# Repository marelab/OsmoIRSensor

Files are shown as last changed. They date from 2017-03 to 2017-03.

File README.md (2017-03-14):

OsmoIRSensor
IR Water &amp; Fluid detection Sensor based on ATTINY45. 
- KiCad Shematic & PCB included under hardware
- Firmware for ATTINY45 included under software

The Sensor was designed for Osmosi waterlevel control. 
It is designed to be full encapsulated in a EPOXY case. 
The hole design an maufacturing process as well as the 
technical backgrounds for the IR detection 
is described under
https://www.marelab.org

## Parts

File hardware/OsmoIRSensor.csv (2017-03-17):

Reference | Value | Footprint | Datasheet | man#
U1 | ATTINY45-S | marelab:SOIC-8 |  | Value
R4 | 10K | Resistors_SMD:R_0805 |  | Value
R3 | 422R | Resistors_SMD:R_0805 |  | Value
R2 | 4K7 | Resistors_SMD:R_0805 |  | Value
R1 | 220R | Resistors_SMD:R_0805 |  | Value
X1 | 20MHz | marelab:RESONATOR |  | Value
D1 | LED PWR | LEDs:LED_0805 |  | Value
D2 | LED IR | LEDs:LED_PLCC-2 |  | Value
U2 | TSOP75436WTR | marelab:SMD-IR |  | Value
J2 | CONN_02X03_PCB_DIRECT | marelab:CON3x2PCB |  | Value
C1 | 22nF | Resistors_SMD:R_0805 |  | Value

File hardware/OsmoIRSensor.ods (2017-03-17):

Reference | Value | Footprint | Datasheet | man# | cost
U1 | ATTINY45-S | marelab:SOIC-8 |  | Value | 1
R4 | 10K | Resistors_SMD:R_0805 |  | Value | 0,1
R3 | 422R | Resistors_SMD:R_0805 |  | Value | 0,1
R2 | 4K7 | Resistors_SMD:R_0805 |  | Value | 0,1
R1 | 220R | Resistors_SMD:R_0805 |  | Value | 0,1
X1 | 20MHz | marelab:RESONATOR |  | Value | 0,5
D1 | LED PWR | LEDs:LED_0805 |  | Value | 0,3
D2 | LED IR | LEDs:LED_PLCC-2 |  | Value | 0,4
U2 | TSOP75436WTR | marelab:SMD-IR |  | Value | 1,1
J2 | CONN_02X03_PCB_DIRECT | marelab:CON3x2PCB |  | Value | 0
C1 | 22nF | Resistors_SMD:R_0805 |  | Value | 0,2
PCB | PCB 1/6 |  |  |  | 0,416666666666667
EpoxyHarz |  |  |  |  | 1,66666666666667
Kabel |  |  |  |  | 6,66666666666667
 |  |  |  | Summe | 12,65

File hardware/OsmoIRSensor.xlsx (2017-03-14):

 |  |  |  |  |  |  | Board Qty: | 100
 |  |  |  |  |  |  | Total Cost: | $0.00 |  |  |  | $0.00 |  |  |  |  |  | $0.00 |  |  |  |  |  | $0.00 |  |  |  |  |  | $0.00
 |  |  |  |  |  |  | Unit Cost: | $0.00
Global Part Info |  |  |  |  |  |  |  |  | Digi-Key |  |  |  |  |  | Mouser |  |  |  |  |  | Newark |  |  |  |  |  | Rs Components
Refs | Value | Desc | Footprint | Manf | Manf# | Qty | Unit$ | Ext$ | Avail | Purch | Unit$ | Ext$ | Cat# | Doc | Avail | Purch | Unit$ | Ext$ | Cat# | Doc | Avail | Purch | Unit$ | Ext$ | Cat# | Doc | Avail | Purch | Unit$ | Ext$ | Cat# | Doc
C1 | 22nF |  | Resistors_SMD:R_0805 |  | Value | 0 | $0.00 | $0.00 |  |  |  |  |  |  | 0 |  | $0.00 | $0.00 | 653-VAL | Link (http://www.mouser.com/Search/../ProductDetail/Omron-Electronics/VAL/?qs=sGAEpiMZZMtzFpQ%252bfsc2VG9FapavGxSS)
IC2 | TSOP75436WTR |  | marelab:SMD-IR |  | Value | 0 | $0.00 | $0.00 |  |  |  |  |  |  | 0 |  | $0.00 | $0.00 | 653-VAL | Link (http://www.mouser.com/Search/../ProductDetail/Omron-Electronics/VAL/?qs=sGAEpiMZZMtzFpQ%252bfsc2VG9FapavGxSS)
IC1 | ATTINY45-S |  | SMD_Packages:SOIC-8-N |  | Value | 0 | $0.00 | $0.00 |  |  |  |  |  |  | 0 |  | $0.00 | $0.00 | 653-VAL | Link (http://www.mouser.com/Search/../ProductDetail/Omron-Electronics/VAL/?qs=sGAEpiMZZMtzFpQ%252bfsc2VG9FapavGxSS)
R2 | 200R |  | Resistors_SMD:R_0805 |  | Value | 0 | $0.00 | $0.00 |  |  |  |  |  |  | 0 |  | $0.00 | $0.00 | 653-VAL | Link (http://www.mouser.com/Search/../ProductDetail/Omron-Electronics/VAL/?qs=sGAEpiMZZMtzFpQ%252bfsc2VG9FapavGxSS)
R3 | 3K |  | Resistors_SMD:R_0805 |  | Value | 0 | $0.00 | $0.00 |  |  |  |  |  |  | 0 |  | $0.00 | $0.00 | 653-VAL | Link (http://www.mouser.com/Search/../ProductDetail/Omron-Electronics/VAL/?qs=sGAEpiMZZMtzFpQ%252bfsc2VG9FapavGxSS)
R4 | 1K |  | Resistors_SMD:R_0805 |  | Value | 0 | $0.00 | $0.00 |  |  |  |  |  |  | 0 |  | $0.00 | $0.00 | 653-VAL | Link (http://www.mouser.com/Search/../ProductDetail/Omron-Electronics/VAL/?qs=sGAEpiMZZMtzFpQ%252bfsc2VG9FapavGxSS)
D1 | LED PWR |  | LEDs:LED_0805 |  | Value | 0 | $0.00 | $0.00 |  |  |  |  |  |  | 0 |  | $0.00 | $0.00 | 653-VAL | Link (http://www.mouser.com/Search/../ProductDetail/Omron-Electronics/VAL/?qs=sGAEpiMZZMtzFpQ%252bfsc2VG9FapavGxSS)
R1 | 10K |  | Resistors_SMD:R_0805 |  | Value | 0 | $0.00 | $0.00 |  |  |  |  |  |  | 0 |  | $0.00 | $0.00 | 653-VAL | Link (http://www.mouser.com/Search/../ProductDetail/Omron-Electronics/VAL/?qs=sGAEpiMZZMtzFpQ%252bfsc2VG9FapavGxSS)
P1 | CONN_02X03_PCB_DIRECT |  | marelab:CON3x2PCB |  | Value | 0 | $0.00 | $0.00 |  |  |  |  |  |  | 0 |  | $0.00 | $0.00 | 653-VAL | Link (http://www.mouser.com/Search/../ProductDetail/Omron-Electronics/VAL/?qs=sGAEpiMZZMtzFpQ%252bfsc2VG9FapavGxSS)
D2 | LED IR |  | LEDs:LED_PLCC-2 |  | Value | 0 | $0.00 | $0.00 |  |  |  |  |  |  | 0 |  | $0.00 | $0.00 | 653-VAL | Link (http://www.mouser.com/Search/../ProductDetail/Omron-Electronics/VAL/?qs=sGAEpiMZZMtzFpQ%252bfsc2VG9FapavGxSS)
Y1 | 20MHz |  | marelab:RESONATOR |  | Value | 0 | $0.00 | $0.00 |  |  |  |  |  |  | 0 |  | $0.00 | $0.00 | 653-VAL | Link (http://www.mouser.com/Search/../ProductDetail/Omron-Electronics/VAL/?qs=sGAEpiMZZMtzFpQ%252bfsc2VG9FapavGxSS)
 |  |  |  |  |  |  |  |  |  | 0 | 0 | 0 |  |  |  | 0 | 0 | 0 |  |  |  | 0 | 0 | 0 |  |  |  | 0 | 0 | 0
 |  |  |  |  |  |  |  |  |  | 0 | 0 | 0 |  |  |  | 0 | 0 | 0 |  |  |  | 0 | 0 | 0 |  |  |  | 0 | 0 | 0
 |  |  |  |  |  |  |  |  |  | 0 | 0 | 0 |  |  |  | 0 | 0 | 0 |  |  |  | 0 | 0 | 0 |  |  |  | 0 | 0 | 0
 |  |  |  |  |  |  |  |  |  | 0 | 0 | 0 |  |  |  | 0 | 0 | 0 |  |  |  | 0 | 0 | 0 |  |  |  | 0 | 0 | 0
 |  |  |  |  |  |  |  |  |  | 0 | 0 | 0 |  |  |  | 0 | 0 | 0 |  |  |  | 0 | 0 | 0 |  |  |  | 0 | 0 | 0
 |  |  |  |  |  |  |  |  |  | 0 | 0 | 0 |  |  |  | 0 | 0 | 0 |  |  |  | 0 | 0 | 0 |  |  |  | 0 | 0 | 0
 |  |  |  |  |  |  |  |  |  | 0 | 0 | 0 |  |  |  | 0 | 0 | 0 |  |  |  | 0 | 0 | 0 |  |  |  | 0 | 0 | 0
 |  |  |  |  |  |  |  |  |  | 0 | 0 | 0 |  |  |  | 0 | 0 | 0 |  |  |  | 0 | 0 | 0 |  |  |  | 0 | 0 | 0
 |  |  |  |  |  |  |  |  |  | 0 | 0 | 0 |  |  |  | 0 | 0 | 0 |  |  |  | 0 | 0 | 0 |  |  |  | 0 | 0 | 0
 |  |  |  |  |  |  |  |  |  | 0 | 0 | 0 |  |  |  | 0 | 0 | 0 |  |  |  | 0 | 0 | 0 |  |  |  | 0 | 0 | 0
 |  |  |  |  |  |  |  |  |  | 0 | 0 | 0 |  |  |  | 0 | 0 | 0 |  |  |  | 0 | 0 | 0 |  |  |  | 0 | 0 | 0

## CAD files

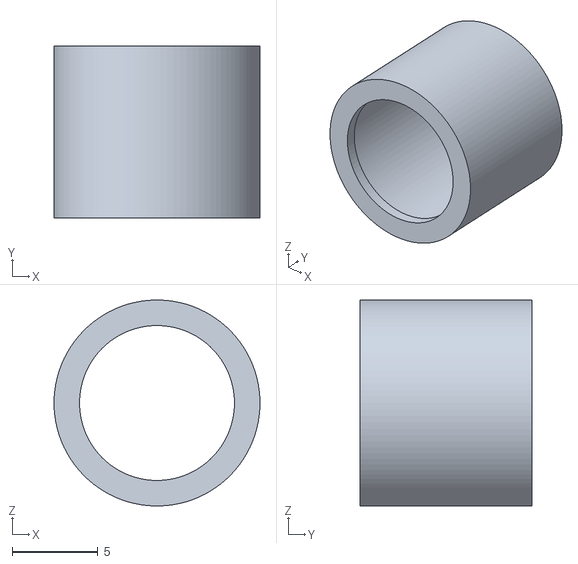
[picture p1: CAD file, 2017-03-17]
3d-prints/opticbarrier.stl
12.0 x 10.0 x 12.0

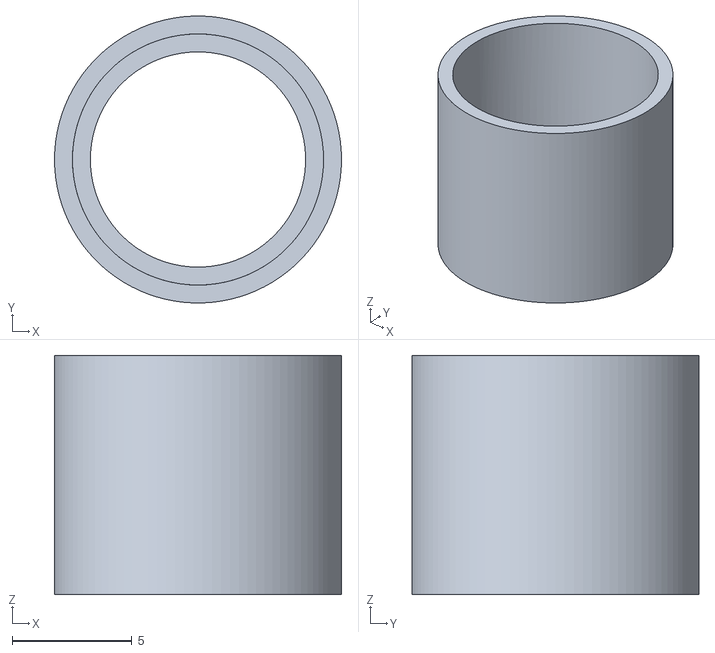
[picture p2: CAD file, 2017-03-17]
3d-prints/opticalBarriere2.stl
12.0 x 12.0 x 10.0

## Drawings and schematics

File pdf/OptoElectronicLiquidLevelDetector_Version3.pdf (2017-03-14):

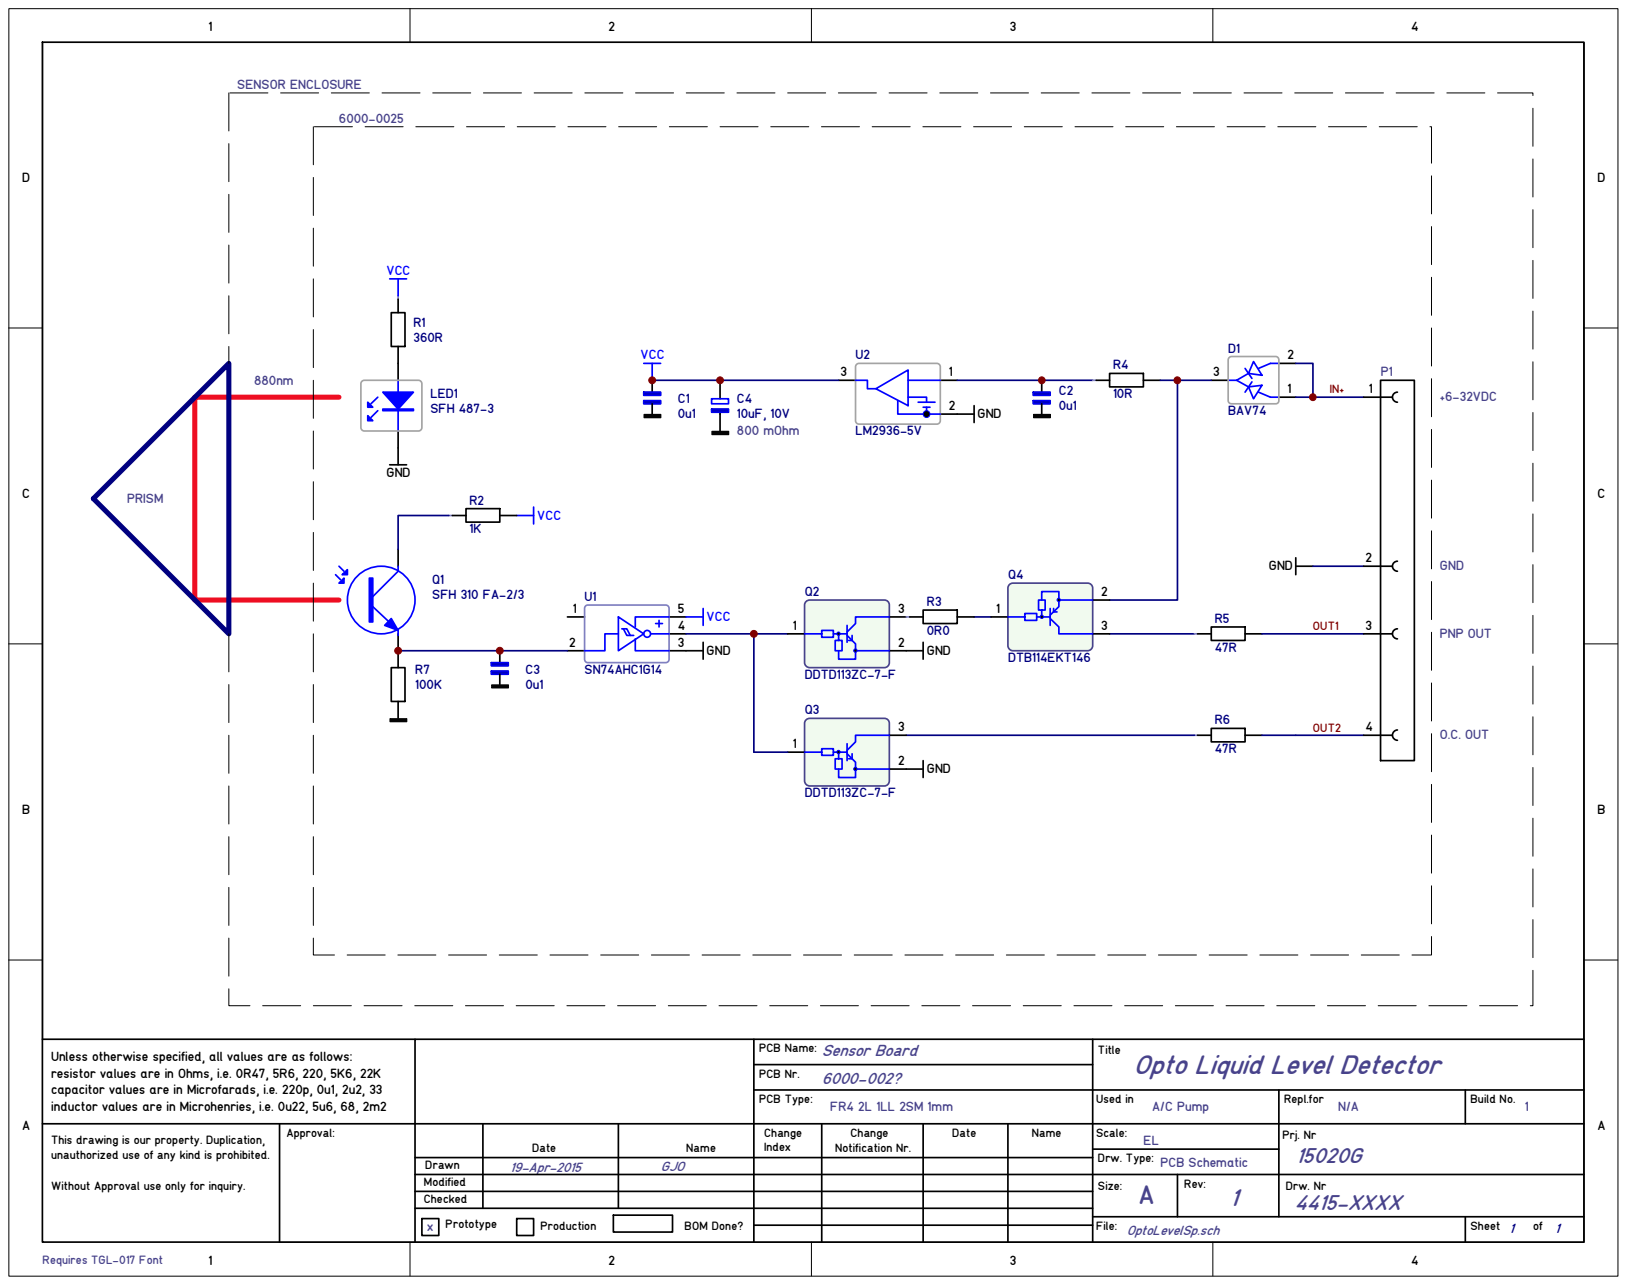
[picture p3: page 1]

PCB Name: Sensor Board

Title
Opto Liquid Level Detector

Unless otherwise specified, all values are as follows:
resistor values are in Ohms, i.e. 0R47, 5R6, 220, 5K6, 22K
capacitor values are in Microfarads, i.e. 220p, 0u1, 2u2, 33
inductor values are in Microhenries, i.e. 0u22, 5u6, 68, 2m2
This drawing is our property. Duplication,
unauthorized use of any kind is prohibited.

Without Approval use only for inquiry.

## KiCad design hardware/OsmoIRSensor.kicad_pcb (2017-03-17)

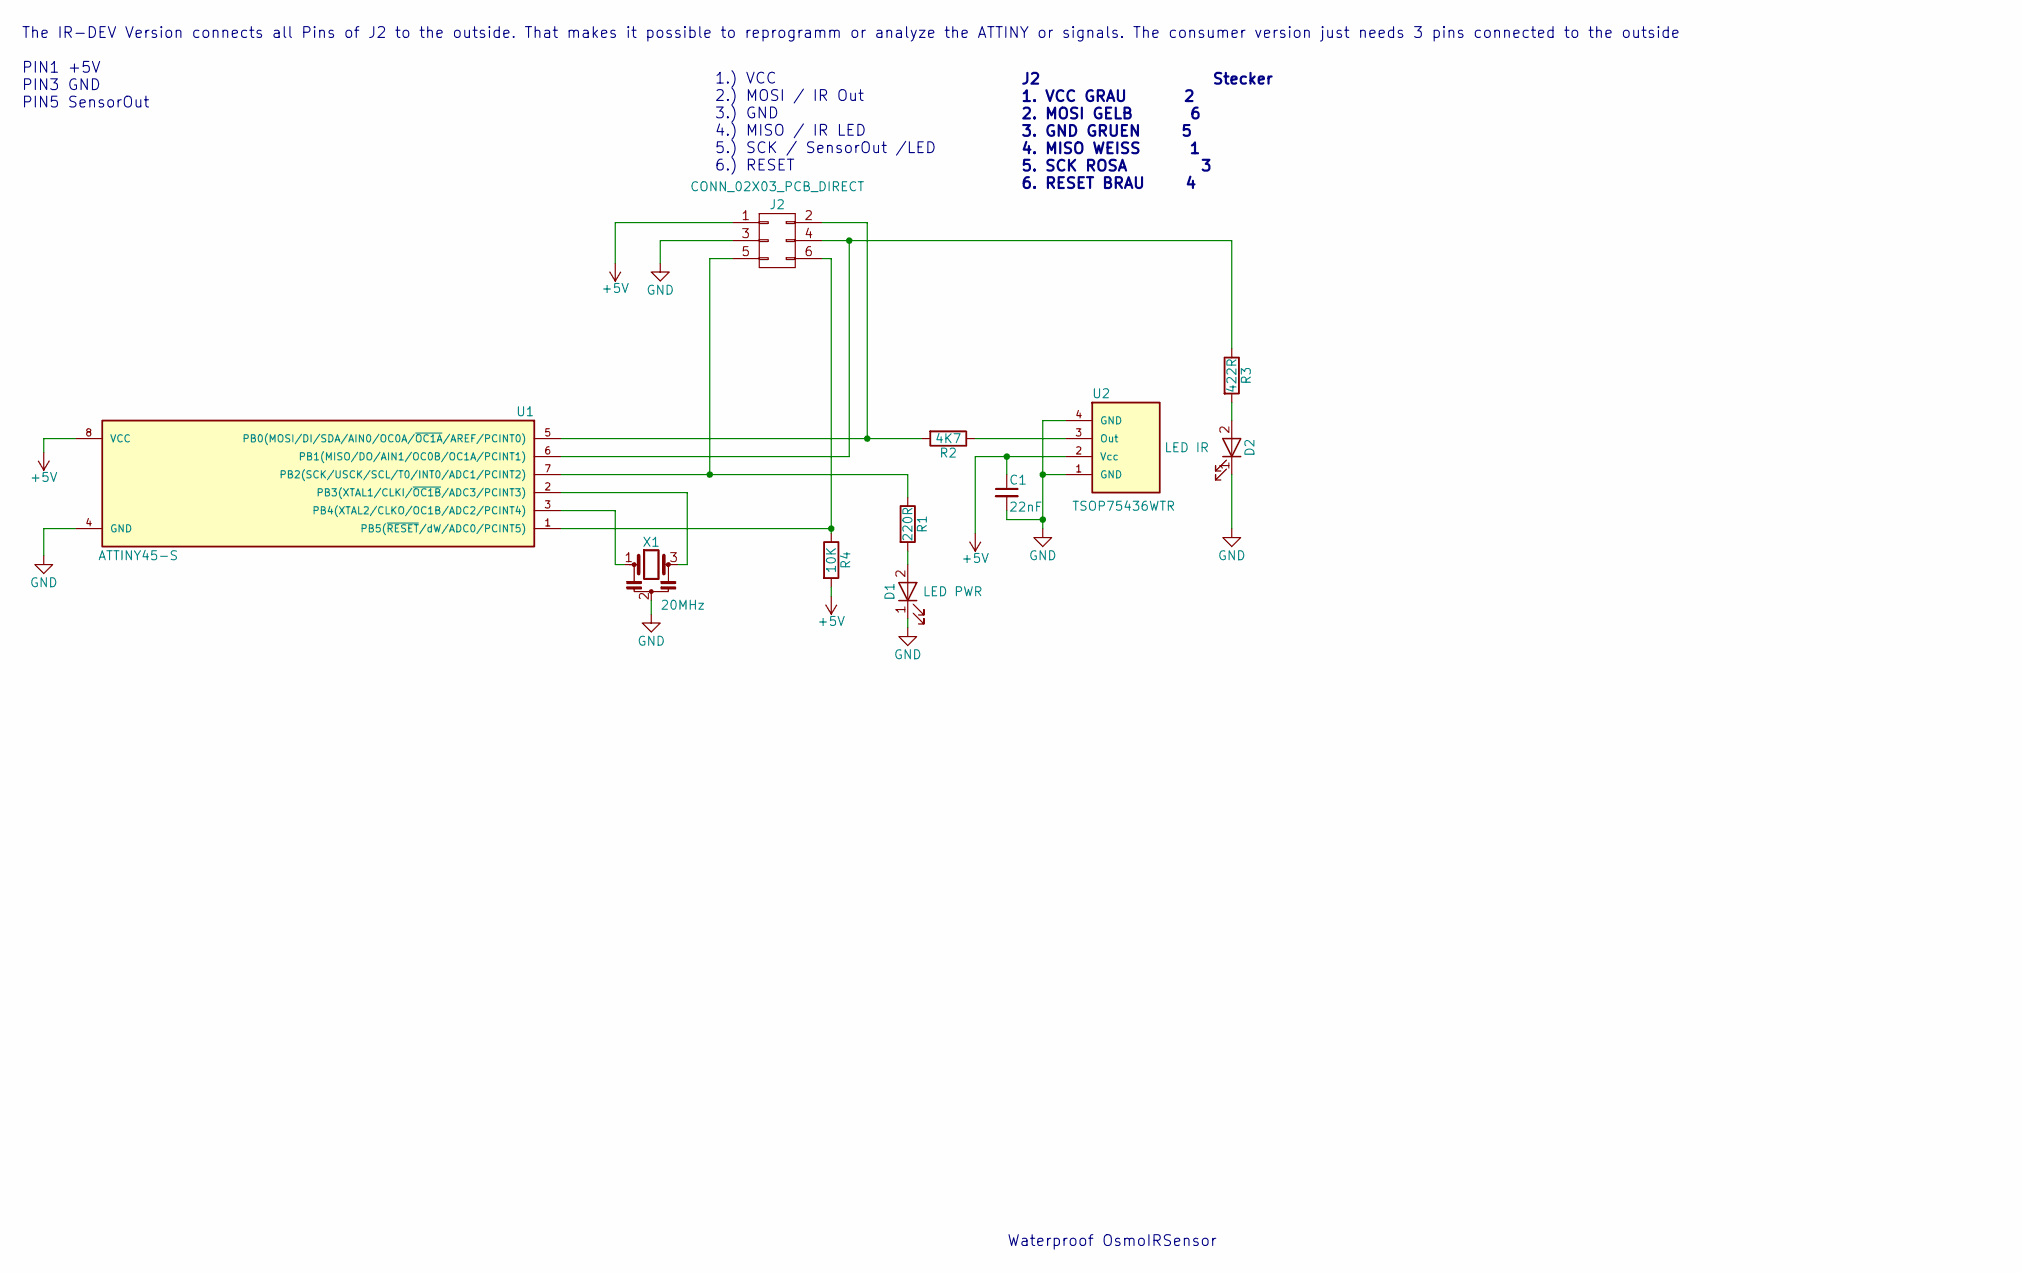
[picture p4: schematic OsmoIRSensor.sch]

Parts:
C1: 22nF; R_0805
D1: LED PWR; LED_0805
D2: LED IR; LED_PLCC-2
J2: CONN_02X03_PCB_DIRECT; CON3x2PCB
R1: 220R; R_0805
R2: 4K7; R_0805
R3: 422R; R_0805
R4: 10K; R_0805
U1: ATTINY45-S; SOIC-8
U2: TSOP75436WTR; SMD-IR
X1: 20MHz; RESONATOR

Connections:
+5V: C1.1, J2.1, R4.2, U1.8 (VCC), U2.2 (Vcc)
GND: C1.2, D1.1 (K), D2.1 (K), J2.3, U1.4 (GND), U2.1 (GND), U2.4 (GND), X1.2
unnamed: D1.2 (A), R1.2
unnamed: D2.2 (A), R3.2
unnamed: J2.2, R2.2, U1.5 (PB0(MOSI/DI/SDA/AIN0/OC0A/~OC1A~/AREF/P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)
unnamed: J2.4, R3.1, U1.6 (PB1(MISO/DO/AIN1/OC0B/OC1A/PCINT1))
unnamed: J2.5, R1.1, U1.7 (PB2(SCK/USCK/SCL/T0/INT0/ADC1/PCINT2))
unnamed: J2.6, R4.1, U1.1 (PB5(~RESET~/dW/ADC0/PCINT5))
unnamed: R2.1, U2.3 (Out)
unnamed: U1.2 (PB3(XTAL1/CLKI/~OC1B~/ADC3/PCINT3)), X1.3
unnamed: U1.3 (PB4(XTAL2/CLKO/OC1B/ADC2/PCINT4)), X1.1

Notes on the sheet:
Waterproof OsmoIRSensor
1.) VCC 2.) MOSI / IR Out 3.) GND 4.) MISO / IR LED 5.) SCK / SensorOut /LED 6.) RESET
The IR-DEV Version connects all Pins of J2 to the outside. That makes it possible to reprogramm or analyze the ATTINY or signals. The consumer version just needs 3 pins connected to the outside PIN1 +5V PIN3 GND PIN5 SensorOut
J2 Stecker 1. VCC GRAU 2 2. MOSI GELB 6 3. GND GRUEN 5 4. MISO WEISS 1 5. SCK ROSA 3 6. RESET BRAU 4

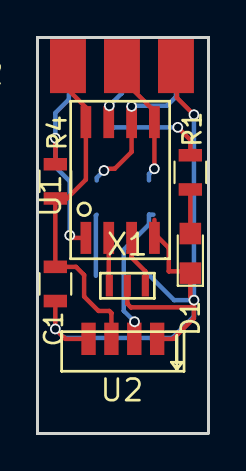
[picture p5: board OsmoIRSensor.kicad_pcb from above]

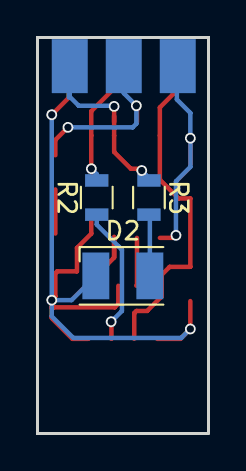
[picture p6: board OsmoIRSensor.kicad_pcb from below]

Board: 2 copper layers, 9.5 x 22.0 mm, 11 parts (3 on the bottom side), 11 nets.

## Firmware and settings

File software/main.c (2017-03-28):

/*
 File		: IR-MARELAB-WATERLEVEL.c
 Created	: 06.02.2017 11:15:52
 Author		: Marc Philipp Hammermann
 mail		: marc@marelab.org
 
 Copyright (C) 2017  by Marc Philpp Hammermann
 
 Program written for ATTINY45 to drive Vishay "AGC P" type proximity sensor. 
 Best results are obtained with a burst length between 100ms and 150ms and a burst period of 500ms or more. The
 TSSP4P38 requires a long idle period for its AGC to recover full sensitivity after repressing the burst.
 
 Timer1 generates PWM thats used for the carrier frquenz 36KHz
 Timer0 used to count length of of Output IR Modulator
 

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
 You should have received a copy of the GNU General Public License along
 with this program; if not, write to the Free Software Foundation, Inc.,
 51 Franklin Street, Fifth Floor, Boston, MA 02110-1301 USA.
  */ 
#include <avr/io.h>
#include <avr/interrupt.h>
#include <stdint.h>
 
 const int BUFFER_SIZE				= 4;        // buffer for serial input, max 3 digits for burst and burstrep
 uint16_t burst						= 0;        // length of burst in ms
 uint16_t burstrep					= 0;        // burst period in ms
 uint16_t burst_count				= 0;        // number of carrier cycles in burst
 uint16_t burstrep_count			= 0;        // number of carrier cycles in burst period
 volatile uint16_t input_capture	= 0;        // counter used to capture the receiver pulse length in timer1
 volatile unsigned long counter     = 0;
 enum {INACTIVE, ACTIVE} state		= INACTIVE; // INACTIVE is waiting for burst times, ACTIVE is where Rx/TX is started or stopped
 enum {PENDING, DONE, BAD} rx_flag	= PENDING;	// PENDING= Rx is capturing a pulse, DONE=Rx captured the pulse
 const uint8_t HALF_PERIOD			= 210;		// (Period_38kHz/2) / Period_16MHz
 const uint8_t DUTY					= 63;		// duty cycle of the 38kHz signal = 30% x HALF_PERIOD (e.g. 30% duty cycle, 30% x HALF_PERIOD = 630)
 
 volatile uint16_t captureLow	= 0;  
 volatile uint16_t captureHigh	= 0;
 volatile uint16_t countOld		= 0;
 
 
// volatile uint16_t input_capture	= 0;        // counter used to capture the receiver pulse length in timer1


static unsigned long carrier_count = 0;       // persistent counter used to count carrier cycles
//static boolean lastState=FALSE;


//*********************************************************************************************************
//  Interrupt service routine
//  Timer2 overflow - used to count carrier cycles
//*********************************************************************************************************

ISR(TIMER1_OVF_vect){
  carrier_count++;							// increment carrier counter
  if (carrier_count == 4000){				// 5700 if burst is completed
    //TCCR1 = (0<<COM1A1)|(0<<COM1A0);      // disconnect OC2B pin driving IR emitter
	TCCR1 &= ~(1<<COM1A1);
	TCCR1 &= ~(1<<COM1A0);
   //DDRB  = (0<<DDB1);
   if ((captureLow *2) < captureHigh){
	   PORTB |= (1 << PB2);    /* LED ON setzt Bit 2 an PortB auf 1 */
	   }else{
	   PORTB &= ~(1 << PB2);   /* LED OFF */
   }
  }											// end if
  if (carrier_count == 8000){				// 16000 if burst cycle is completed
    TCCR1 |= (1<<COM1A1);
	TCCR1 |= (1<<COM1A0);					// re-connect OC2B pin driving IR emitter
	// Prepare Signal for water or dry
	carrier_count	= 0;					// reset counter for start of new cycle
	captureHigh	    = 0;                    // new cycle reset all
	captureLow		= 0;
	countOld        = 0;
  }											
}                                          

//*********************************************************************************************************
//  Interrupt service routine
//  PIN INTERRUPT TO MEASURE TIME
//  This detects if the sensor is in/out of water
//  Time is measured between Interrupts of any edge change
//*********************************************************************************************************
// Die länge zwischen zwei Interrupts messen und bestimmen ob es Low oder High war
 
ISR(PCINT0_vect){
	if((PINB & (1 << PB0))) {
		//Flanke von LOW nach HIGH
		captureLow = captureLow + (carrier_count - countOld); 
	}else
	{
		// Flanke von High nach Low
		captureHigh = captureHigh + (carrier_count - countOld); 
		
	}
	countOld = carrier_count;
}                                          // end ISR


void setup() {  
  // Timer 1 Fast  PWM
  TCCR1		=  (1<<PWM1A)  | (0<<CS13)| (0<<CS12)| (1<<CS11) | (0<<CS10);
  GTCCR		=  (0<<PWM1B);
  TCCR1		|= (1<<COM1A1)|(1<<COM1A0);
  OCR1A		=  80; // Duty
  OCR1C		=  255;
  TCNT1		=  0;
  TIMSK		= (0 << OCIE1B) | (0 << OCIE1A) | (1 << TOIE1);
  DDRB		|= (1<<DDB1);
  // -------------------------------------
  
  // Pin Interrupt setup
  GIMSK		|= (1<<PCIE);
  //MCUCR     |= (1<<ISC00);			//  Any logical change on INT0 generates an interrupt request. 
 // GIMSK		|= (1<<INT0);			// External Interrupt Request 0 Enable
  PCMSK		|= (1<<PCINT0)|(0<<PCINT1)|(0<<PCINT2)|(0<<PCINT3)|(0<<PCINT4)|(0<<PCINT5); // PB0 Pin as Input for Interrupt its the output of the IR Transreceiver
  DDRB	    |= (0<<DDB0);
  PORTB		 = 0x01;
  // -------------------------------------
  
  // Ausgabe Port
  DDRB				|= (1<<DDB2) ;
  sei();							// a formality, interrupts enabled in IDE
  burst				= 150;			// convert ASCII to integer
  burst_count		= burst * 38;	// calculate number of modulation cycles in burst
  burstrep_count	= 400 * 38;		// calculate number of modulation cycles in burst period
  state				= ACTIVE;		// state may now send and receive

}                                         


int main(void)
{
  setup();
  //*********************************************************************************************************
  //  Get user variables for burst length and repetition time. Calculate no. of carrier
  //  cycles for each. Set machine state to ACTIVE.
  //*********************************************************************************************************
  //*********************************************************************************************************
  //   Main routine where the action happens
  //*********************************************************************************************************
  while(state == ACTIVE){
        
  }                                         // end while
}

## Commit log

2017-03-14 Marelab IR Water Sensor Initial Version
    [OsmoIRSensor.csv, OsmoIRSensor.kicad_pcb, OsmoIRSensor.ods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]
2017-03-17 - Corrected IC Pads Size - Gerber Files added for 10x9,1cm panelized pcb - 3D Printer Files for optical Barrier added - Pin Desc. for DEV Cabel
    [OsmoIRSensor.csv, OsmoIRSensor.kicad_pcb, OsmoIRSensor.ods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]
2017-03-28 - Sensor Interrupt Handling changed - 20MHz Fuse Setting no CHKDIV/8

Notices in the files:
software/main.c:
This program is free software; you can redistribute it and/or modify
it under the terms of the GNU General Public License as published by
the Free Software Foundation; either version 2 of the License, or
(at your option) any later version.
